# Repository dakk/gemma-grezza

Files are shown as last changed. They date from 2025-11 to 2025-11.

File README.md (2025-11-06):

# Gemma Grezza - My UncutGem build

These are my edits, files and notes from my attempt to build UncutGem from Quantum Village, a Full Stack fully Open Source NV Center Diamond Magnetometer. If you want to build one, go to [Quantum Village website](https://quantumvillage.org/#test-site-intro-md) and [UncutGem github](https://github.com/QuantumVillage/UncutGem/).

## What I've done differently
- used a [custom mold](./mold) for casting the diamond 
- created a [3d printable enclosure](./model)
- build a [pcb in Kicad](./pcb)
- made some modifications to the [firmware](./firmware)
- added a button to interact with the device

## Firmware

The firmware is a custom modification of the original; in particular # TODO

## Build process & results

The build process is told in this blogpost: # TODO

## Licensing

This project is under the [Affero GPL license](./LICENSE) as the original UncutGem project. This is a paritcularly restrictive license that demands any and all updates from anyone using this project. The AGPL is designed specifically to ensure that any modified material becomes available to the community. Specifically:

> Notwithstanding any other provision of this License, if you modify the Program, your modified version must prominently offer all users interacting with it remotely through a computer network (if your version supports such interaction) an opportunity to receive the Corresponding Source of your version by providing access to the Corresponding Source from a network server at no charge, through some standard or customary means of facilitating copying of software. [...]

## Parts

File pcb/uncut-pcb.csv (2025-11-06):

'Reference' | 'Value' | 'Footprint' | 'Datasheet' | 'Qty' | 'DNP' | 'Exclude from BOM' | 'Exclude from Board'
'C1,C2' | '104' | 'Capacitor_THT:C_Disc_D7.5mm_W2.5mm_P5.00mm' | '~' | '2' | '' | '' | ''
'C3,C4,C5,C6,C9,C10' | '100nF' | 'Capacitor_THT:C_Disc_D7.5mm_W2.5mm_P5.00mm' | '~' | '6' | '' | '' | ''
'C7,C8' | '10uF' | 'Capacitor_THT:CP_Radial_D4.0mm_P2.00mm' | '~' | '2' | '' | '' | ''
'D1' | 'LED' | 'LED_THT:LED_D3.0mm' | '~' | '1' | '' | '' | ''
'J1' | 'ADC_SIGNAL' | 'Connector_PinHeader_1.00mm:PinHeader_1x01_P1.00mm_Vertical' | '~' | '1' | '' | '' | ''
'J2' | 'LASER' | 'Connector_JST:JST_EH_B2B-EH-A_1x02_P2.50mm_Vertical' | '~' | '1' | '' | '' | ''
'J3' | 'FN_RST_BTN' | 'Connector_JST:JST_EH_B3B-EH-A_1x03_P2.50mm_Vertical' | '~' | '1' | '' | '' | ''
'J4' | 'PHOTODIODE' | 'Connector_JST:JST_EH_B3B-EH-A_1x03_P2.50mm_Vertical' | '~' | '1' | '' | '' | ''
'J5' | 'SIGGEN' | 'Connector_PinHeader_2.54mm:PinHeader_2x04_P2.54mm_Vertical' | '~' | '1' | '' | '' | ''
'J6' | '5V_TERM' | 'Connector_JST:JST_EH_B2B-EH-A_1x02_P2.50mm_Vertical' | '~' | '1' | '' | '' | ''
'J7' | 'OLED' | 'Connector_JST:JST_EH_B4B-EH-A_1x04_P2.50mm_Vertical' | '~' | '1' | '' | '' | ''
'Q1' | '2N2222' | 'Package_TO_SOT_THT:TO-92' | 'https://ngspice.sourceforge.io/docs/ngspice-html-manual/manual.xhtml#cha_BJTs' | '1' | '' | '' | ''
'R1,R2,R3,R4,R5,R7' | '1k' | 'Resistor_THT:R_Axial_DIN0204_L3.6mm_D1.6mm_P7.62mm_Horizontal' | '~' | '6' | '' | '' | ''
'R6' | '300' | 'Resistor_THT:R_Axial_DIN0204_L3.6mm_D1.6mm_P7.62mm_Horizontal' | '~' | '1' | '' | '' | ''
'U1' | 'ESP32-DevKitC' | 'PCM_Espressif:ESP32-DevKitC' | 'https://docs.espressif.com/projects/esp-idf/zh_CN/latest/esp32/hw-reference/esp32/get-started-devkitc.html' | '1' | '' | '' | ''
'U2' | 'TL072' | 'Package_DIP:DIP-8_W7.62mm' | 'http://www.ti.com/lit/ds/symlink/tl071.pdf' | '1' | '' | '' | ''

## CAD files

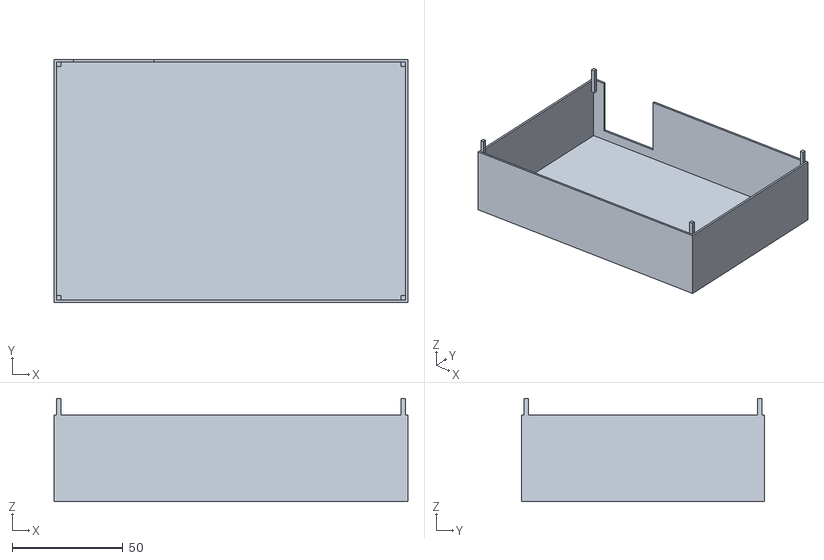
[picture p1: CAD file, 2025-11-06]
model/uncut_top.stl
160.0 x 110.0 x 46.7

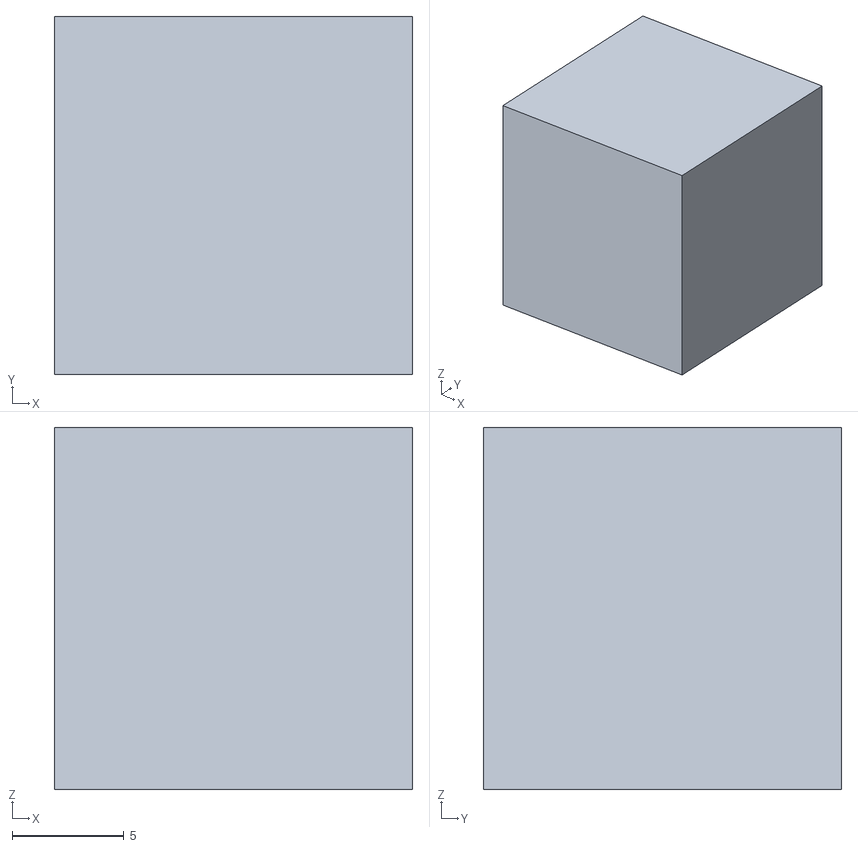
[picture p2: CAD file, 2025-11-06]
mold/uncut_gem_mold_10.stl
16.0 x 16.0 x 16.2

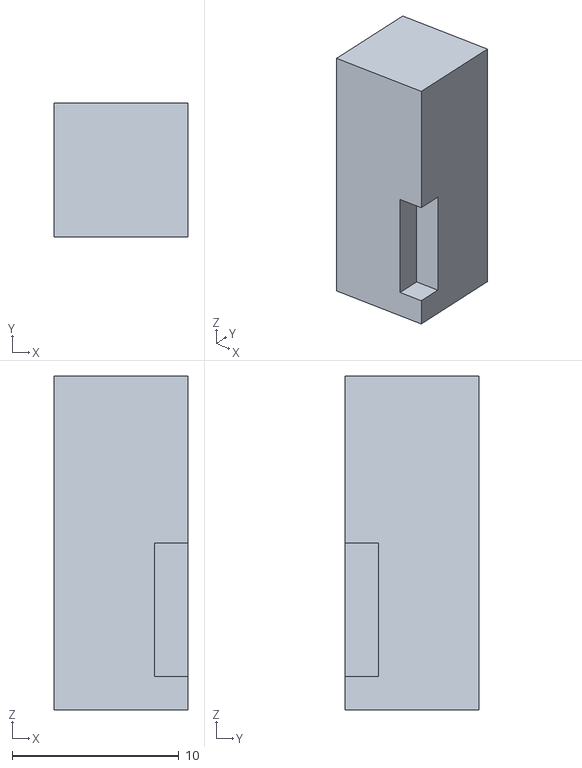
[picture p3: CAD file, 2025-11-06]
model/top_supports.stl
8.00 x 8.00 x 20.0

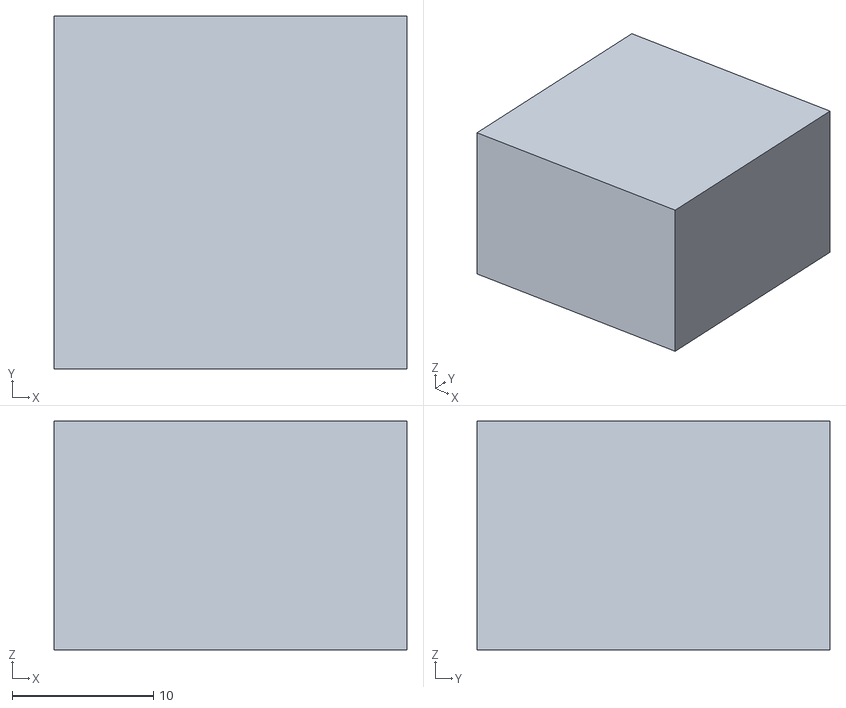
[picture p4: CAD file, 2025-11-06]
mold/uncut_gem_mold.stl
25.0 x 25.0 x 16.2

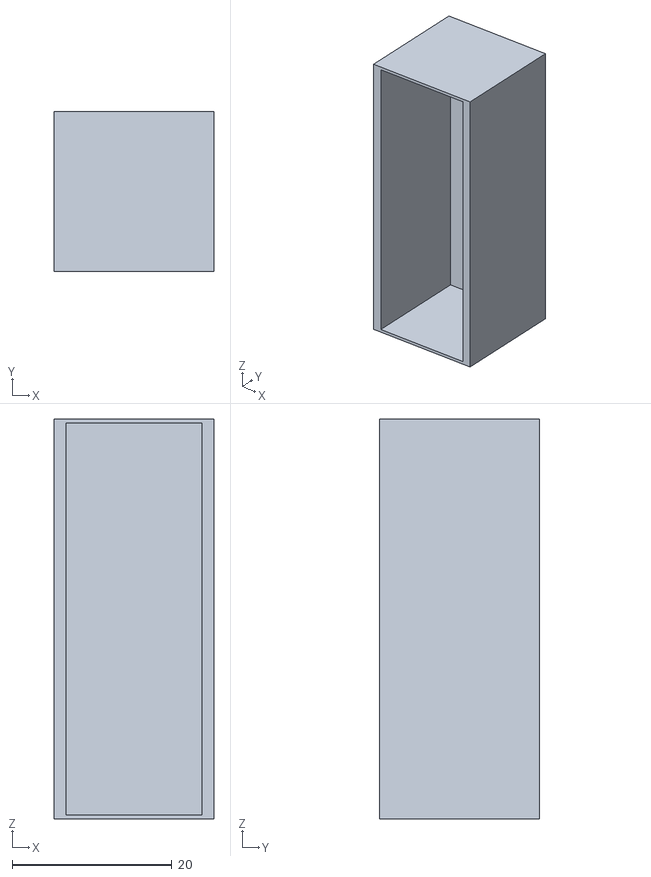
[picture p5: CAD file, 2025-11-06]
model/laser_cover.stl
20.0 x 20.0 x 50.0

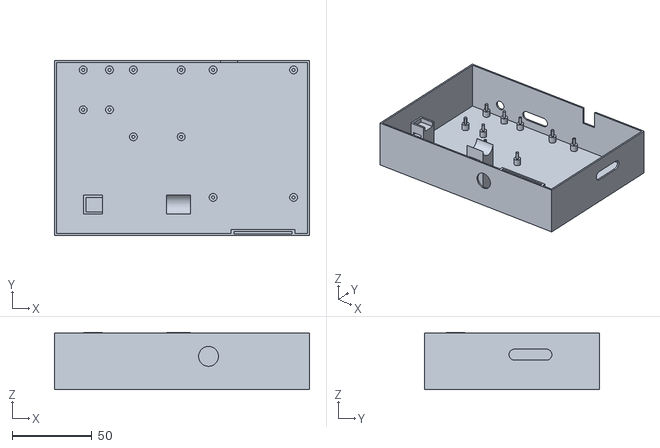
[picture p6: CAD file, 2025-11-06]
model/uncut_case.stl
160.0 x 110.0 x 35.8

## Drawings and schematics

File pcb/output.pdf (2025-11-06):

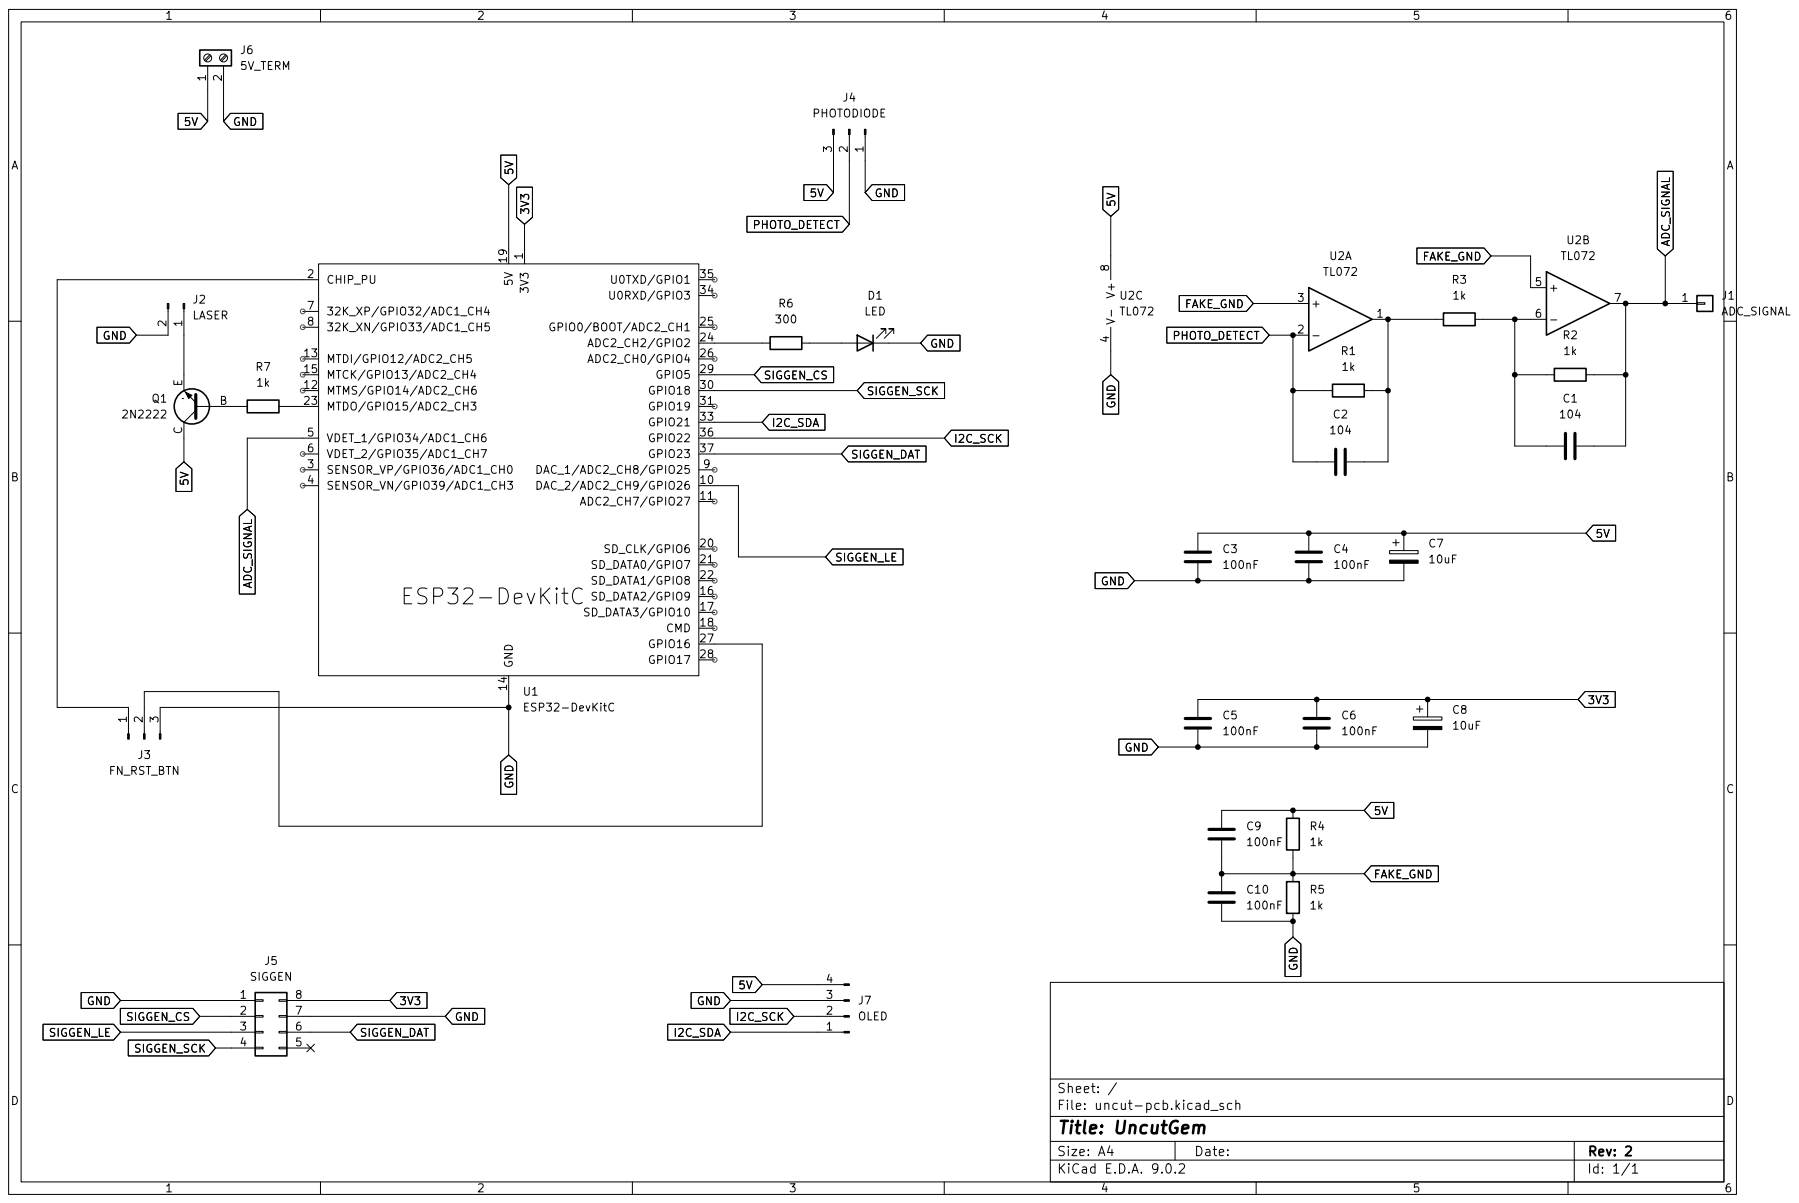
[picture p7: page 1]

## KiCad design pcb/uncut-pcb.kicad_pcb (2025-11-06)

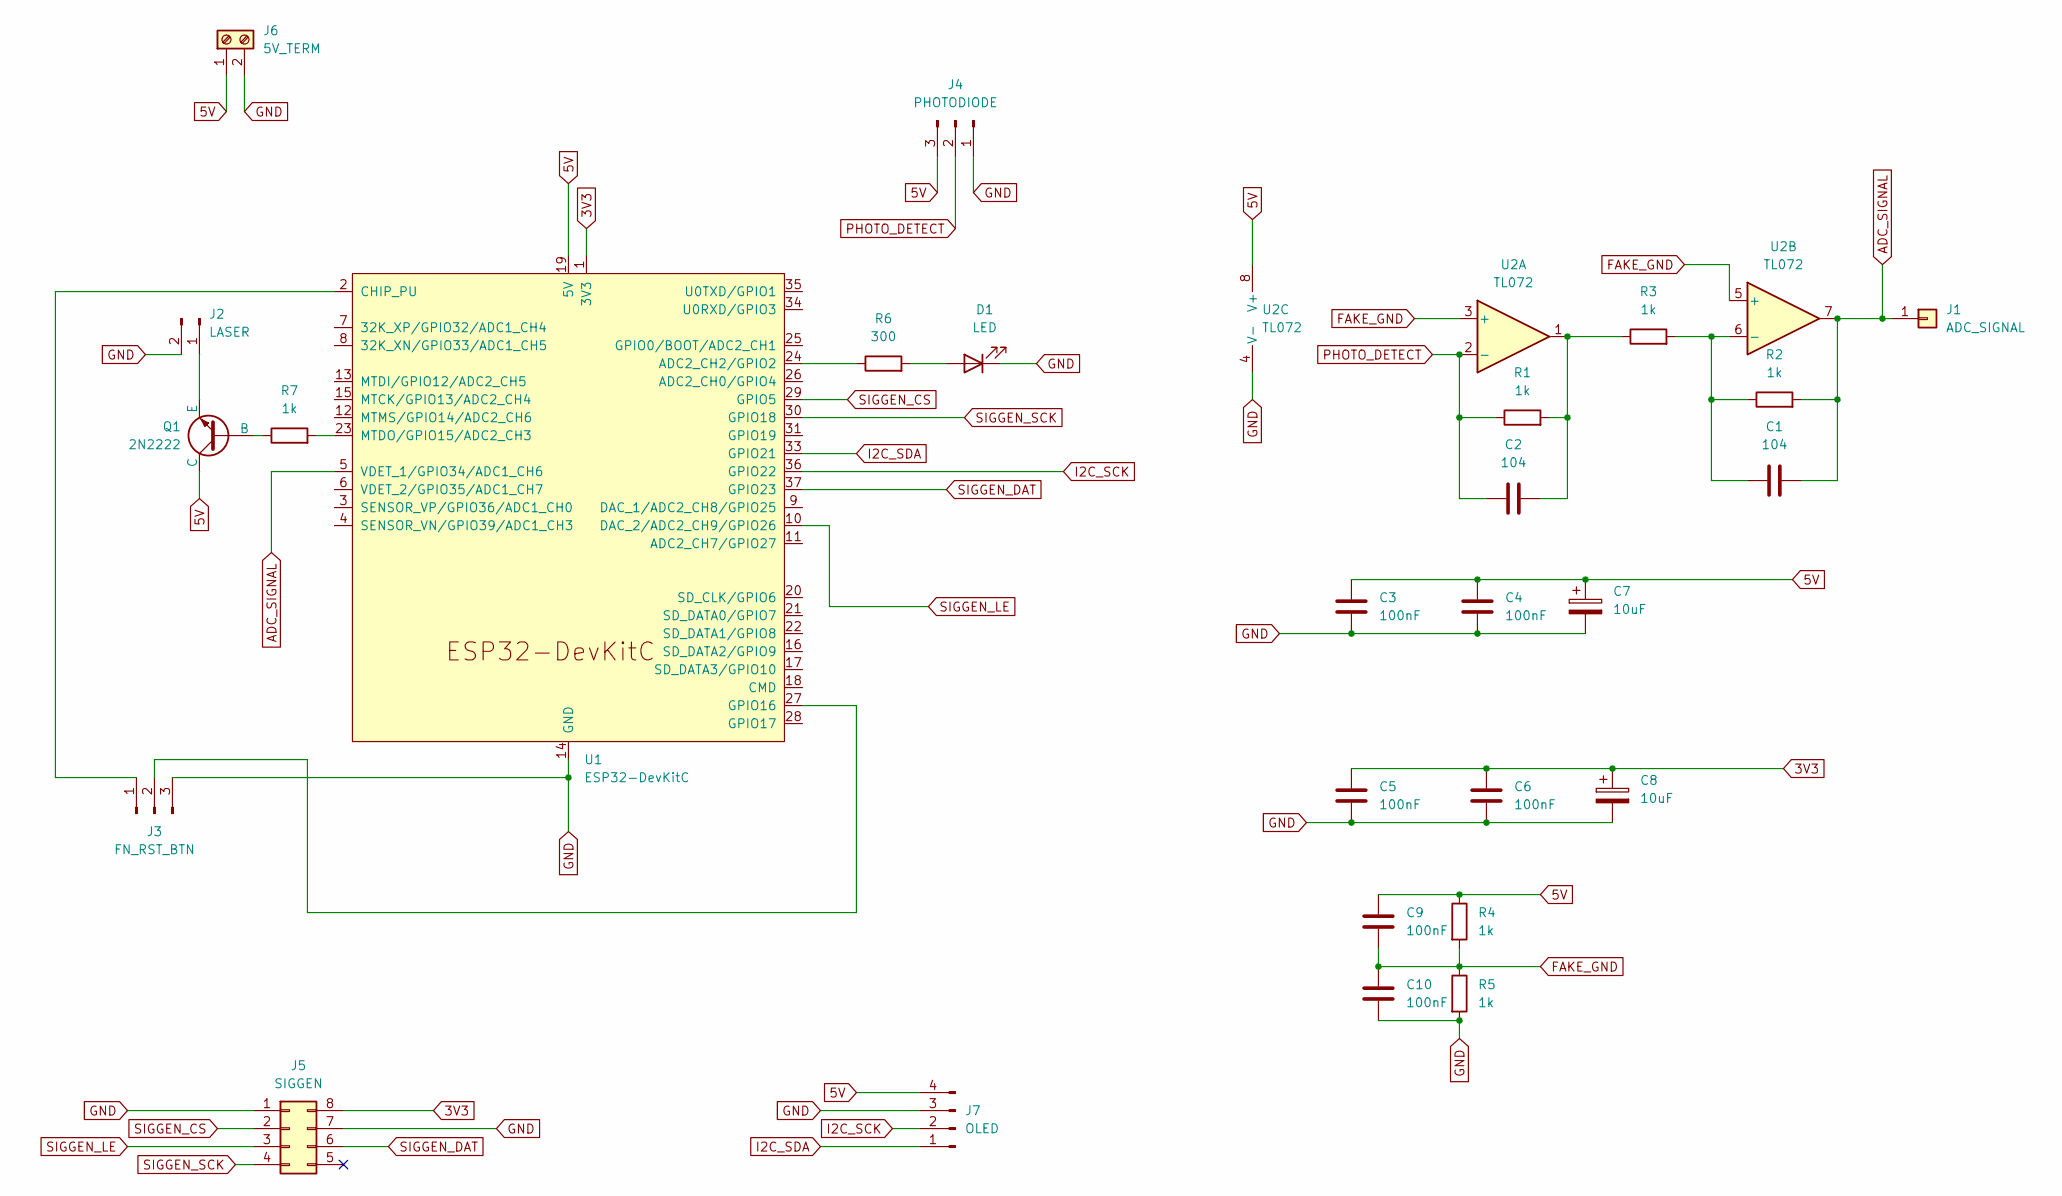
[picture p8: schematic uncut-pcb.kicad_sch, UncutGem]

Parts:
C1, C2: 104; C_Disc_D7.5mm_W2.5mm_P5.00mm
C3, C4, C5, C6, C9, C10: 100nF; C_Disc_D7.5mm_W2.5mm_P5.00mm
C7, C8: 10uF; CP_Radial_D4.0mm_P2.00mm
D1: LED; LED_D3.0mm
J1: ADC_SIGNAL; PinHeader_1x01_P1.00mm_Vertical
J2: LASER; JST_EH_B2B-EH-A_1x02_P2.50mm_Vertical
J3: FN_RST_BTN; JST_EH_B3B-EH-A_1x03_P2.50mm_Vertical
J4: PHOTODIODE; JST_EH_B3B-EH-A_1x03_P2.50mm_Vertical
J5: SIGGEN; PinHeader_2x04_P2.54mm_Vertical
J6: 5V_TERM; JST_EH_B2B-EH-A_1x02_P2.50mm_Vertical
J7: OLED; JST_EH_B4B-EH-A_1x04_P2.50mm_Vertical
Q1: 2N2222; TO-92
R1, R2, R3, R4, R5, R7: 1k; R_Axial_DIN0204_L3.6mm_D1.6mm_P7.62mm_Horizontal
R6: 300; R_Axial_DIN0204_L3.6mm_D1.6mm_P7.62mm_Horizontal
U1: ESP32-DevKitC
U2: TL072; DIP-8_W7.62mm

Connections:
3V3: C5.1, C6.1, C8.1, J5.8, U1.1 (3V3)
5V: C3.1, C4.1, C7.1, C9.1, J4.3, J6.1, J7.4, Q1.1 (C), R4.1, U1.19 (5V), U2.8 (V+)
ADC_SIGNAL: C1.2, J1.1, R2.2, U1.5 (VDET_1/GPIO34/ADC1_CH6), U2.7
FAKE_GND: C9.2, C10.1, R4.2, R5.1, U2.3 (+), U2.5 (+)
GND: C3.2, C4.2, C5.2, C6.2, C7.2, C8.2, C10.2, D1.1 (K), J2.2, J3.3, J4.1, J5.1, J5.7, J6.2, J7.3, R5.2, U1.14 (GND), U1.32 (GND), U1.38 (GND), U2.4 (V-)
I2C_SCK: J7.2, U1.36 (GPIO22)
I2C_SDA: J7.1, U1.33 (GPIO21)
unnamed: C2.2, R1.2, R3.1, U2.1
unnamed: D1.2 (A), R6.2
unnamed: J2.1, Q1.3 (E)
unnamed: J3.1, U1.2 (CHIP_PU)
unnamed: J3.2, U1.27 (GPIO16)
unnamed: Q1.2 (B), R7.1
unnamed: R6.1, U1.24 (ADC2_CH2/GPIO2)
unnamed: R7.2, U1.23 (MTDO/GPIO15/ADC2_CH3)
unnamed: C1.1, R2.1, R3.2, U2.6 (-)
PHOTO_DETECT: C2.1, J4.2, R1.1, U2.2 (-)
SIGGEN_CS: J5.2, U1.29 (GPIO5)
SIGGEN_DAT: J5.6, U1.37 (GPIO23)
SIGGEN_LE: J5.3, U1.10 (DAC_2/ADC2_CH9/GPIO26)
SIGGEN_SCK: J5.4, U1.30 (GPIO18)

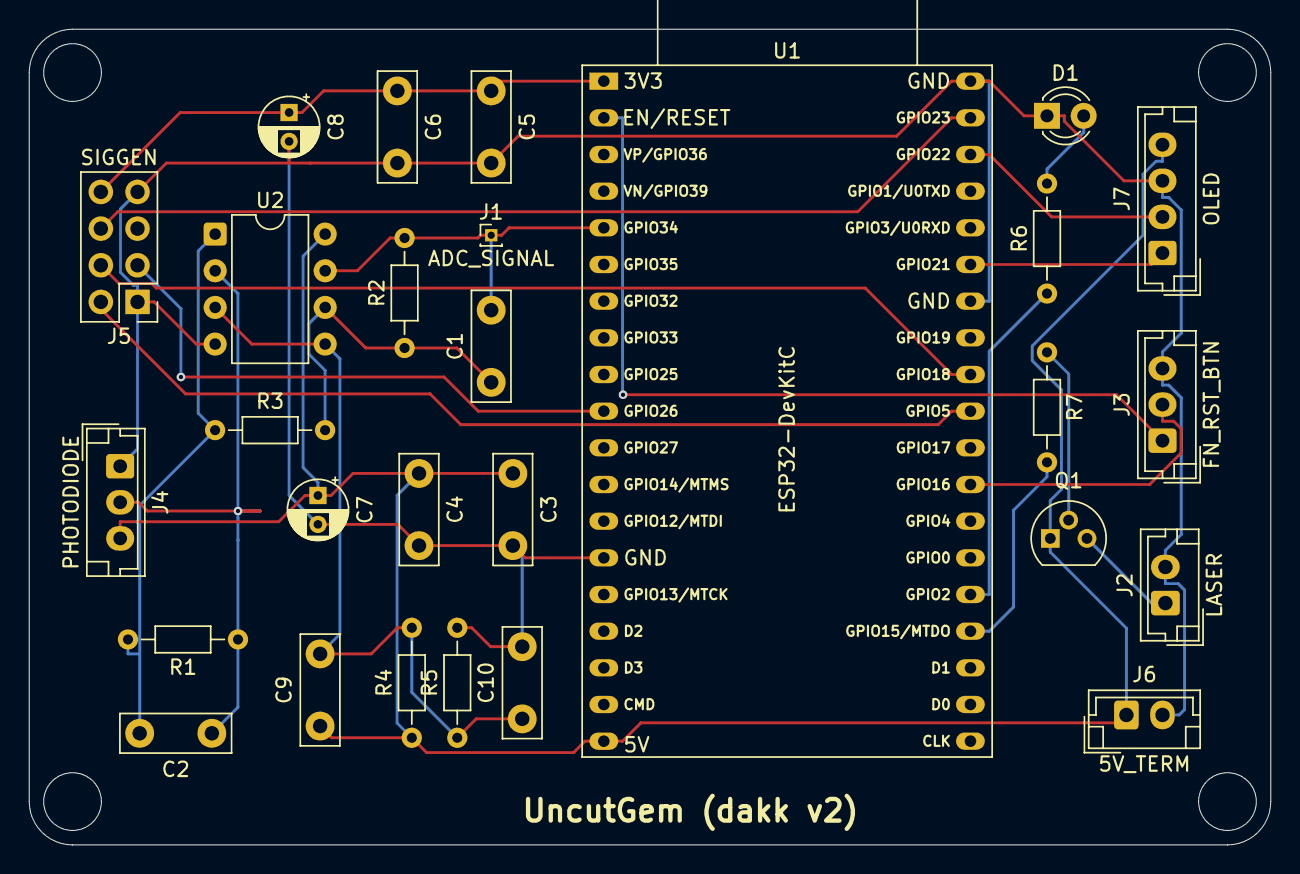
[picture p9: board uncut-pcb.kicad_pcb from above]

Board: 2 copper layers, 86.0 x 56.5 mm, 28 parts (0 on the bottom side), 21 nets.

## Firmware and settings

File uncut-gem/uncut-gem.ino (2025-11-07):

#include <SPI.h>
#include <OneButton.h>
#include <adf4350.h>
#include <Wire.h>
#include <Adafruit_GFX.h>
#include <Adafruit_SH110X.h>

#define I2C_ADDRESS 0x3c
#define SCREEN_WIDTH 128 // OLED display width, in pixels
#define SCREEN_HEIGHT 64 // OLED display height, in pixels
#define OLED_RESET -1   //   QT-PY / XIAO

#define LED_PIN 2
#define LASER_PIN 15
#define FN_BTN_PIN 16 

#define COM_PIN 26 //32 // sets pin 26 to be the slave-select pin for PLL
#define ADC_PIN 35

ADF4350 PLL(COM_PIN, ADC_PIN); // declares object PLL of type ADF4350. Will initialize it below.
Adafruit_SH1106G display = Adafruit_SH1106G(SCREEN_WIDTH, SCREEN_HEIGHT, &Wire, OLED_RESET);
OneButton fn_btn = OneButton(FN_BTN_PIN, true, true);

int MINVAL_ADC = 1750;
int MAXVAL_ADC = 1500; // moved to adf4350.h
int VAL_DIV = 11;
int CALIBRATION_COUNT = 10;
int CUM_PLOT_SCALE = 1375; // cumulative plot scaling base
int CUM_PLOT_DIV = 3;//1.5; // cumulative plot divider 
int PT_OFFSET = 7;

int prev_val = 0;
int cum_ctr = 0; // cumulative counter


enum AppState { SENSOR, COMPUTER, RNG, MENU };
AppState currentState = SENSOR; // MENU;
int menuIndex = 0;
const char* menuItems[] = { "Quantum sensor", "Quantum computer", "Quantum RNG" };
const char* title = "UncutGem 1.0";
const int menuLength = 3;

void drawMenu() {
  display.clearDisplay();
  display.setTextSize(1);
  display.setTextColor(SH110X_WHITE);
  display.setCursor(2, 2);
  display.println(title);

  for (int i = 0; i < menuLength; i++) {
    display.setCursor(5, 20 + i * 12);
    if (i == menuIndex) {
      display.print("> ");
    } else {
      display.print("  ");
    }
    display.println(menuItems[i]);
  }
  display.display();
}

static void handleClick() {
  Serial.println("Clicked!");

  if(currentState == MENU) {
    menuIndex = (menuIndex + 1) % menuLength;
  }
}

static void handleDoubleClick() {
  Serial.println("Double clicked!");

}

static void handleLongClick() {
  Serial.println("Long clicked!");

  if(currentState == MENU) {
    currentState = static_cast<AppState>(menuIndex);
    Serial.println(currentState);
    display.clearDisplay();
    display.setCursor(0, 0);
    display.setTextSize(1);
    display.setTextColor(SH110X_WHITE);
    display.print("Starting ");
    display.println(menuItems[menuIndex]);
    display.display();
    delay(1000);
  } else {
    currentState = MENU;
  }
}

void setup(){
  delay(250); // wait for the OLED to power up
  display.begin(I2C_ADDRESS, true); // Address 0x3C default
  pinMode(LED_PIN, OUTPUT);
  pinMode(LASER_PIN, OUTPUT);

  digitalWrite(LED_PIN, HIGH);
  digitalWrite(LASER_PIN, HIGH);
  
  Serial.begin(115200) ;


  display.clearDisplay();
  display.setTextSize(1);
  display.setTextColor(SH110X_WHITE);
  display.setCursor(2, 2);
  display.println(title);
  display.display();
  Serial.println(title);

  fn_btn.attachClick(handleClick);
  fn_btn.attachDoubleClick(handleDoubleClick);
  fn_btn.attachLongPressStop(handleLongClick);

   while(!Serial){};
  delay(250); // give it a sec to warm up
  Serial.println("PPL initialization...");
  PLL.init(2870, 10);
  delay(500);
  digitalWrite(LED_PIN, LOW);
  delay(1000);
  digitalWrite(LED_PIN, HIGH);
  Serial.println("PPL sending 2870...");
  PLL.send_2870();
  digitalWrite(LED_PIN, LOW);
  delay(2000);
  Serial.println("PPL sending sweep...");
  PLL.send_sweep();
  Serial.println("PPL initialized.");
  calibrate();
  digitalWrite(LED_PIN, HIGH);
}

void loop() {
  fn_btn.tick();

  switch (currentState) {
    case MENU:
      drawMenu();
      // delay(3000);
      // display.clearDisplay();
      // currentState = SENSOR;
      break;

    case SENSOR:
      loopSensor();
      break;

    case COMPUTER:
      display.clearDisplay();
      display.setCursor(0, 0);
      display.println("Quantum computer");
      display.display();
      delay(2000);
      currentState = MENU;
      break;

    case RNG:
      display.clearDisplay();
      display.setCursor(0, 0);
      display.println("RNG");
      display.display();
      delay(2000);
      currentState = MENU;
      break;
  }
}


void loopSensor() {
  // digitalWrite(LASER_PIN, HIGH);

  display.clearDisplay();
  display.setTextSize(1);
  display.setTextColor(SH110X_WHITE);
  display.setCursor(2, 2);
  display.println("Sensing...");

  int cum_avg = 0; // cumulative average
  for(int i = 0; i < 128; i++){
    int ADC_out = PLL.send_sweep_step(i);
    display.drawLine(i, display.height(), i, 25, SH110X_BLACK); // clear the existing line
    int display_val = (((ADC_out - MINVAL_ADC )/ VAL_DIV) + prev_val)/2; // interpolate the previous value
    display.drawLine(i, display.height(), i, display.height() - min(display_val, 40), SH110X_WHITE);
    display.display();
    //Serial.println(display_val);
    cum_avg += ADC_out;
    prev_val = display_val; // using this prev_val gives some interpolation to make the graph clearer
  }
  cum_avg /= 128;
  // display.setTextSize(1);
  // display.setTextColor(SH110X_WHITE);
  // display.setCursor(100, 0);
  // display.println(cum_avg);
  // display.display();

  // do a small 25px cumulative average plot
  if (cum_ctr > 127){ cum_ctr = 0; display.fillRect(0, 0, 128, 64, SH110X_BLACK);}
  float scaled_val = ((cum_avg - (float)CUM_PLOT_SCALE)/(float)CUM_PLOT_DIV);
  int dot_val = scaled_val < 0 ? floor(scaled_val)/2 : scaled_val; // if dot_val is negative, scale it to 'small near zero'
  dot_val = (dot_val - PT_OFFSET) * 1.5;
  display.drawPixel(cum_ctr, dot_val, SH110X_WHITE);
  display.display();
  // Serial.println(scaled_val);
  cum_ctr++;

  // digitalWrite(LASER_PIN, LOW);
  delay(100);
}

void calibrate(){
  // digitalWrite(LASER_PIN, HIGH);
  // warm up the microwave generator and it's gain stage,
  // then characterize it and calibrate the values for scaling for display.
  Serial.println("Calibrating...");
  display.clearDisplay();
  display.setTextSize(1);
  display.setTextColor(SH110X_WHITE);
  display.setCursor(2, 2);
  display.println("Calibrating...");
  display.display();
  int ctr = 0;
  int cum_avg = 0;
  int max_ca = 0;
  do{ // warm-up run
    for(int i = 0; i < 128; i++){
      int ADC_out = PLL.send_sweep_step(i);
    }
    ctr++;
  }while(ctr < CALIBRATION_COUNT);
  ctr = 0;
  do {
    int cum_avg = 0;
    for(int i = 0; i < 128; i++){
      int ADC_out = PLL.send_sweep_step(i);
      cum_avg += ADC_out;
      if (ADC_out > MAXVAL_ADC){
        MAXVAL_ADC = ADC_out;
      }
      if (ADC_out < MINVAL_ADC && ADC_out > 1100){ 
        // reduce it, but not below 1.1V...
        MINVAL_ADC = ADC_out-25;
      }
    }
    ctr++;
    cum_avg /= 128;
    if (cum_avg < CUM_PLOT_SCALE) {CUM_PLOT_SCALE = cum_avg + 25;}
    if (cum_avg > max_ca) {max_ca = cum_avg;}
  }while(ctr < CALIBRATION_COUNT);
  CUM_PLOT_DIV = ((max_ca - CUM_PLOT_SCALE) / 25) + 2;
  VAL_DIV = (MAXVAL_ADC - MINVAL_ADC)/40; 
  
  // if (VAL_DIV == 0)
  //   VAL_DIV = 1;

  display.clearDisplay();
  // digitalWrite(LASER_PIN, LOW);
}

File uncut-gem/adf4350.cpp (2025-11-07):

/* 
   ADF4350.cpp - ADF4350 PLL Communication Library
   Created by Neal Pisenti, 2013.
   JQI - Strontium - UMD

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

 */

#include "Arduino.h"
#include "SPI.h"
#include <adf4350.h>
#include <sweep_array.h>



// NOTE: Currently, set up for channel spacing of 10Mhz; might ammend later if needed,
//  but this was easy and takes care of forseeable applications...
//  This means we'll be operating in int-N mode.
//  
//  Currently, keep frequency between 140Mhz and 3Ghz.

/* CONSTRUCTOR */

// Constructor function; initializes communication pinouts

ADF4350::ADF4350(byte LEPin, byte ADC_pin) {
    _LEPin = LEPin;
    _ADCpin = ADC_pin;
    pinMode(_LEPin, OUTPUT);
    digitalWrite(_LEPin, HIGH);
    // setup ESP32 SPI object
    spi = new SPIClass(VSPI);
    spi->begin(SPI_SCLK, SPI_MISO, SPI_MOSI, SPI_SS);
}


// Initializes a new ADF4350 object, with refClk (in Mhz), and initial frequency.
void ADF4350::init(int freq, int refClk = 10){
    _refClk = refClk;
    _phase = 1;

    _feedbackType = 0;
    _powerdown = 0;
    _auxEnabled = 0;
    _rfEnabled = 1;

    // default power = 5dbm
    _auxPower = 3;
    _rfPower = 3;

    // sets register values which don't have dynamic values...
    ADF4350::setR1();
    ADF4350::setR3();
    ADF4350::setR5();


    ADF4350::setFreq(freq);
    // ADF4350::update();
}

// gets current frequency setting
int ADF4350::getFreq(){
    return _freq;
}

void ADF4350::setFreq(int freq){
    /*
    THIS IS BS (PROFESSIONAL ASSESSMENT) -MC
    _freq = freq;
    int multiplier;

    // selects the right divider range (ie, output divider is 2^(_divider))
    // the multiplier is required if you're using fundamental feedback to N-counter
    if (_freq <= 270 && _freq >= 140){
        _divider = 4;
        multiplier = 16;
    } else if (_freq >= 280 && _freq <= 540){
        _divider = 3;
        multiplier = 8;
    } else if (_freq >= 550 && _freq <= 1090){
        _divider = 2;
        multiplier = 4;
    } else if (_freq >= 1100 && _freq <= 2190){
        _divider = 1;
        multiplier = 2;
    } else{
        _divider = 0;
        multiplier = 1;
    }

    if (_feedbackType == 0){
        _int = _freq/_refClk;
    } else{
        _int = _freq*multiplier/_refClk;
    } */
    //ADF4350::update();
}



// updates dynamic registers, and writes values to PLL board
void ADF4350::update(){
    // updates registers with dynamic values...
    ADF4350::setR0();
    ADF4350::setR2();
    ADF4350::setR4();

    // writes registers to device
    ADF4350::writeRegister(_r5);
    ADF4350::writeRegister(_r4);
    ADF4350::writeRegister(_r3);
    ADF4350::writeRegister(_r2);
    ADF4350::writeRegister(_r1);
    ADF4350::writeRegister(_r0);
}

void ADF4350::setFeedbackType(bool feedback){
    _feedbackType = feedback;
}

void ADF4350::powerDown(bool pd){
    _powerdown = pd;
    ADF4350::setR2();
    ADF4350::update();

}

void ADF4350::rfEnable(bool rf){
    _rfEnabled = rf;
    ADF4350::setR4();
    ADF4350::update();
}

// CAREFUL!!!! pow must be 0, 1, 2, or 3... corresponding to -4, -1, 3, 5 dbm.
void ADF4350::setRfPower(int pow){
    _rfPower = pow;
    ADF4350::setR4();
    ADF4350::update();
}

void ADF4350::auxEnable(bool aux){
    _auxEnabled = aux;
    ADF4350::setR4();
    ADF4350::update();
}

// CAREFUL!!!! pow must be 0, 1, 2, or 3... corresponding to -4, -1, 3, 5 dbm.
void ADF4350::setAuxPower(int pow){
    _auxPower = pow;
    ADF4350::setR4();
    ADF4350::update();
}

// REGISTER UPDATE FUNCTIONS

void ADF4350::setR0(){
    unsigned long r0 = (_int << 15); // sets int value...
    byte r0Ary[] = { lowByte(r0 >> 24), lowByte(r0 >> 16), lowByte(r0 >> 8), lowByte(r0) };
    memcpy(&_r0, &r0Ary, sizeof(r0Ary));
}

void ADF4350::setR1(){
    unsigned long r1 =   (_phase << 15) + // phase value = 1
            (2 << 3) + // modulus value = 1
             1; // register value
    byte r1Ary[] = { lowByte(r1 >> 24), lowByte(r1 >> 16), lowByte(r1 >> 8), lowByte(r1) };
    memcpy(&_r1, &r1Ary, sizeof(r1Ary));
}

void ADF4350::setR2(){
    unsigned long r2 =   (6 << 26) +  // muxout
            (1 << 14) +  // r-counter = 1
            (7 << 9) +  // charge pump = 2.5
            (5 << 6) +  // digital lock detect + polarity
            (_powerdown << 5) +   // powerdown 0 = false; 1 = true
            2; // register value
    
    byte r2Ary[] =  { lowByte(r2 >> 24), lowByte(r2 >> 16), lowByte(r2 >> 8), lowByte(r2) };
    memcpy(&_r2, &r2Ary, sizeof(r2Ary));
}

void ADF4350::setR3(){
   unsigned long r3 =  3; // (all zero, except register control value = 3);
   byte r3Ary[] = { lowByte(r3 >> 24), lowByte(r3 >> 16), lowByte(r3 >> 8), lowByte(r3) };
   memcpy(&_r3, &r3Ary, sizeof(r3Ary));
}

void ADF4350::setR4(){

    unsigned long r4 = (_feedbackType << 23) + // divided/fundamental feedback
        (_divider << 20) +
        (80 << 12) + // band select clock divider
        (0 << 9) + // vco powerdown = false; MTLD = 1; aux output = divided;
        (_auxEnabled << 8) + // AUX OUTPUT enable/disable
        (_auxPower << 6) + // aux output power = {-4, -1, 2, 5dbm}
        (_rfEnabled << 5) + // RF OUTPUT ENABLED
        (_rfPower << 3) + // RF output power = 5dbm
        4;  // register select

   byte r4Ary[] = { lowByte(r4 >> 24), lowByte(r4 >> 16), lowByte(r4 >> 8), lowByte(r4) };
   memcpy(&_r4, &r4Ary, sizeof(r4Ary));


}

void ADF4350::setR5(){

  unsigned long r5 = (1 << 22) + (3<<19) + 5; // lock detect pin mode = digital lock detect
  byte r5Ary[] = { lowByte(r5 >> 24), lowByte(r5 >> 16), lowByte(r5 >> 8), lowByte(r5) };
  memcpy(&_r5, &r5Ary, sizeof(r5Ary));

}

void ADF4350::send_2870(){
  // mamually calculated
  byte dataArr[6][5] = {{5, 0x00, 0x58, 0x00, 0x05},
                        {4, 0x00, 0x86, 0x43, 0x24},
                        {3, 0x00, 0x04, 0x00, 0x03},
                        {2, 0x20, 0x00, 0xBE, 0x42},
                        {1, 0x00, 0x00, 0x80, 0x29},
                        {0, 0x00, 0x72, 0x80, 0x18}};
  for(int i = 0; i < 6; i++){
    byte tmp[4]; // this isn't necessary, it's just testing for the below. -MC
    for(int j = 0; j < 4; j++){
      tmp[j] = dataArr[i][j+1];
    }
    ADF4350::writeRegister(tmp);
  }
}


// Sooty's mad... so he's gonna send Soo and he's gonna...
void ADF4350::send_sweep(){
  for(int i = 0; i < 128; i++){
    for(int j = 0; j < 6; j++){
      if (sweepArr[i][j][0] == 6) {
        continue; // skip this register...
      }
      byte tmp[4];
      for(int s = 0; s < 4; s++){
        tmp[s] = sweepArr[i][j][s+1];
      } //, tmp[1], tmp[2], tmp[3]);
      ADF4350::writeRegister(tmp);
    }
    // delayMicroseconds(500);
    delay(1);
    int ADC_out = ADF4350::get_avg_ADC();
    // ok now take some readings and print them to Serial
    Serial.println(ADC_out);
  }
}
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

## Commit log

2025-11-06 pcb and models
    [laser_cover.stl, top_supports.stl, uncut_case.stl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]
2025-11-06 pcb update
    [uncut-pcb.csv, uncut-pcb.kicad_pcb, uncut-pcb.kicad_sch]

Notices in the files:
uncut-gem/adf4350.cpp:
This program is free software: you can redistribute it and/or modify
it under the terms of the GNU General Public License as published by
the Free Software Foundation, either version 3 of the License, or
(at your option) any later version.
